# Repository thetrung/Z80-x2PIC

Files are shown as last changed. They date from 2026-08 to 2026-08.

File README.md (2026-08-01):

# Z80 Homebrew with Dual 8-bit PIC 
Another PCB made for Z80 + 2x PIC18F4520 to debug, test-run & verify code.

### Note
I have never had a real working Z80 before so this board is designed to test that if I can get one.

### 3D Preview 
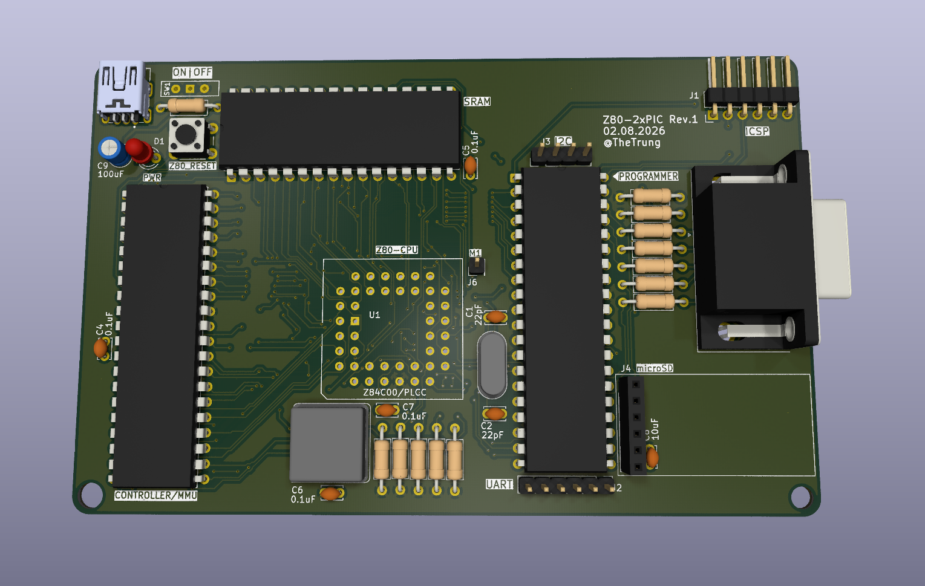
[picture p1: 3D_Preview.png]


### Placement (SilkScreen)
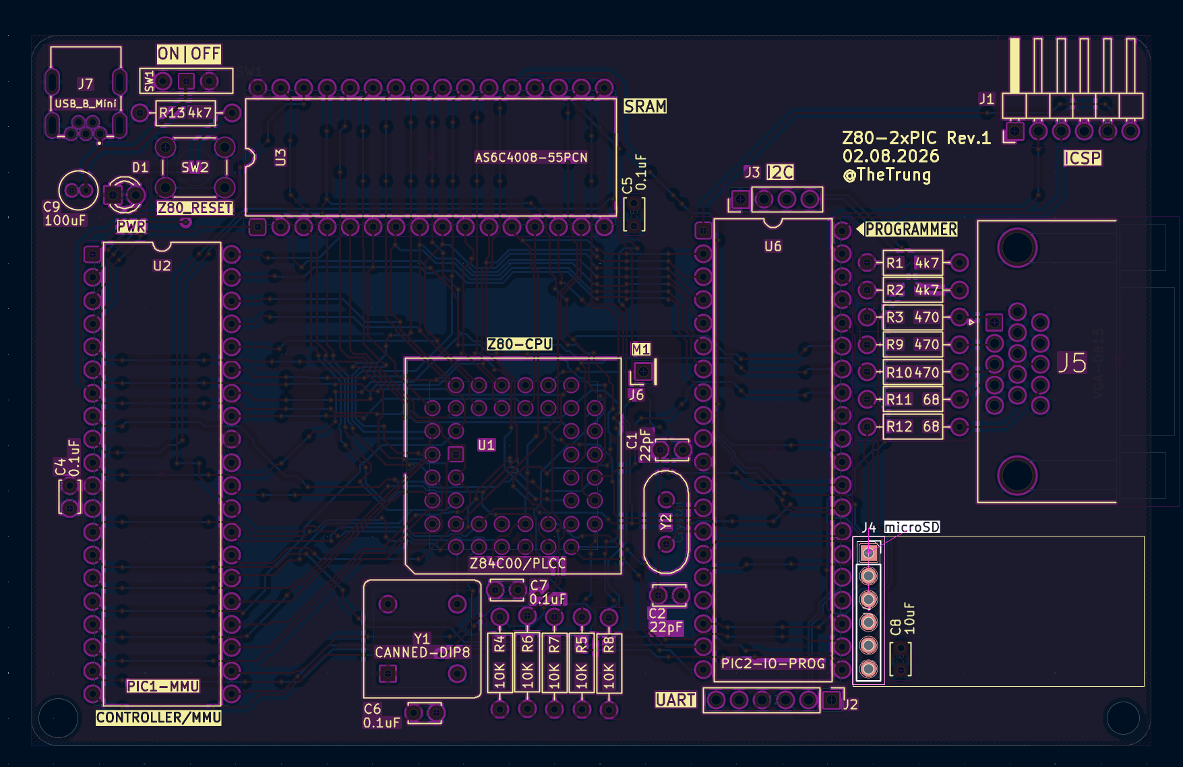
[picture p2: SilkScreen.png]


### Schematic 
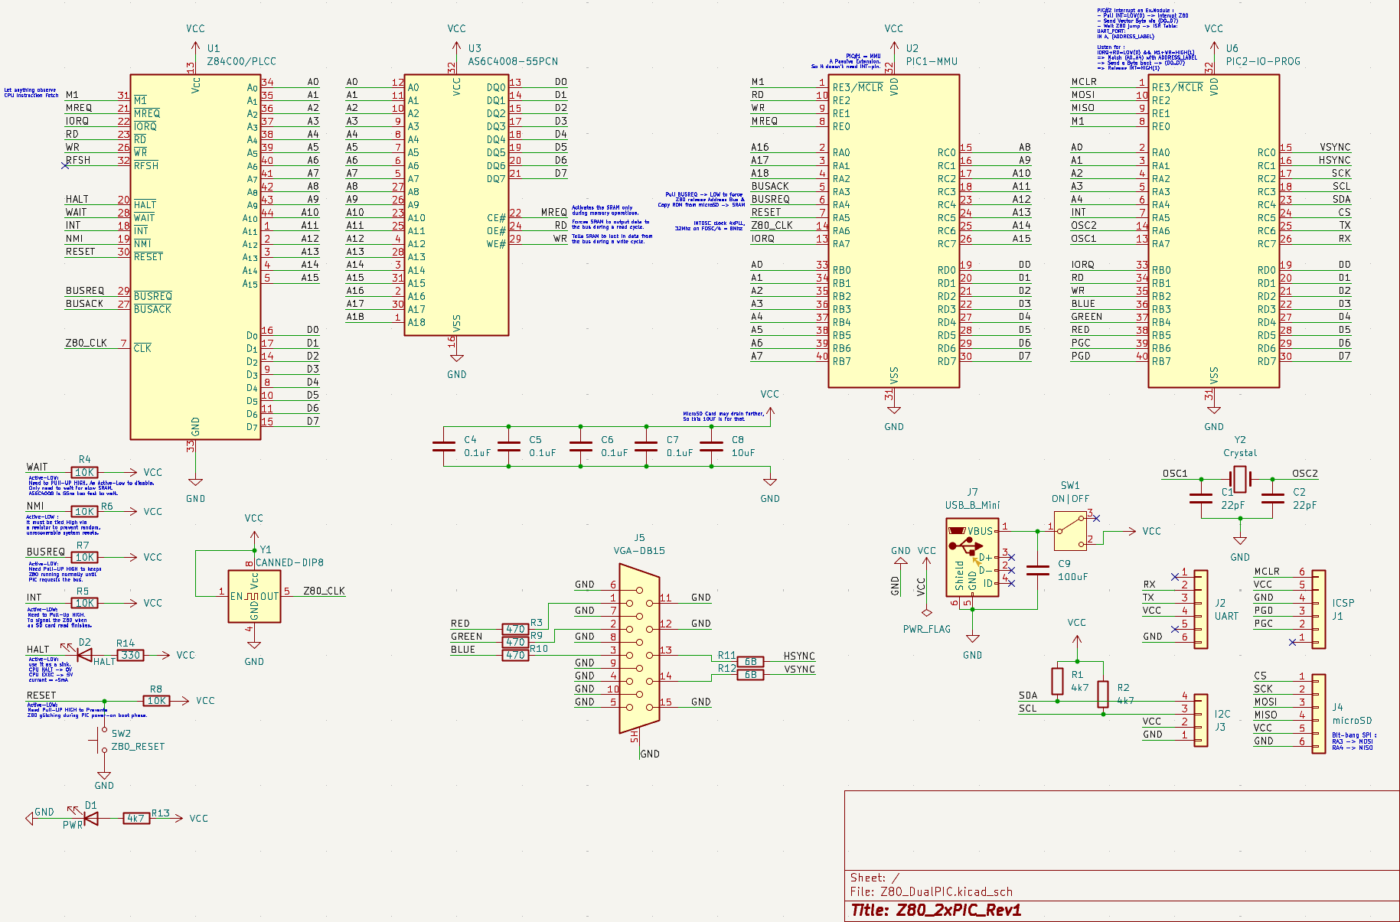
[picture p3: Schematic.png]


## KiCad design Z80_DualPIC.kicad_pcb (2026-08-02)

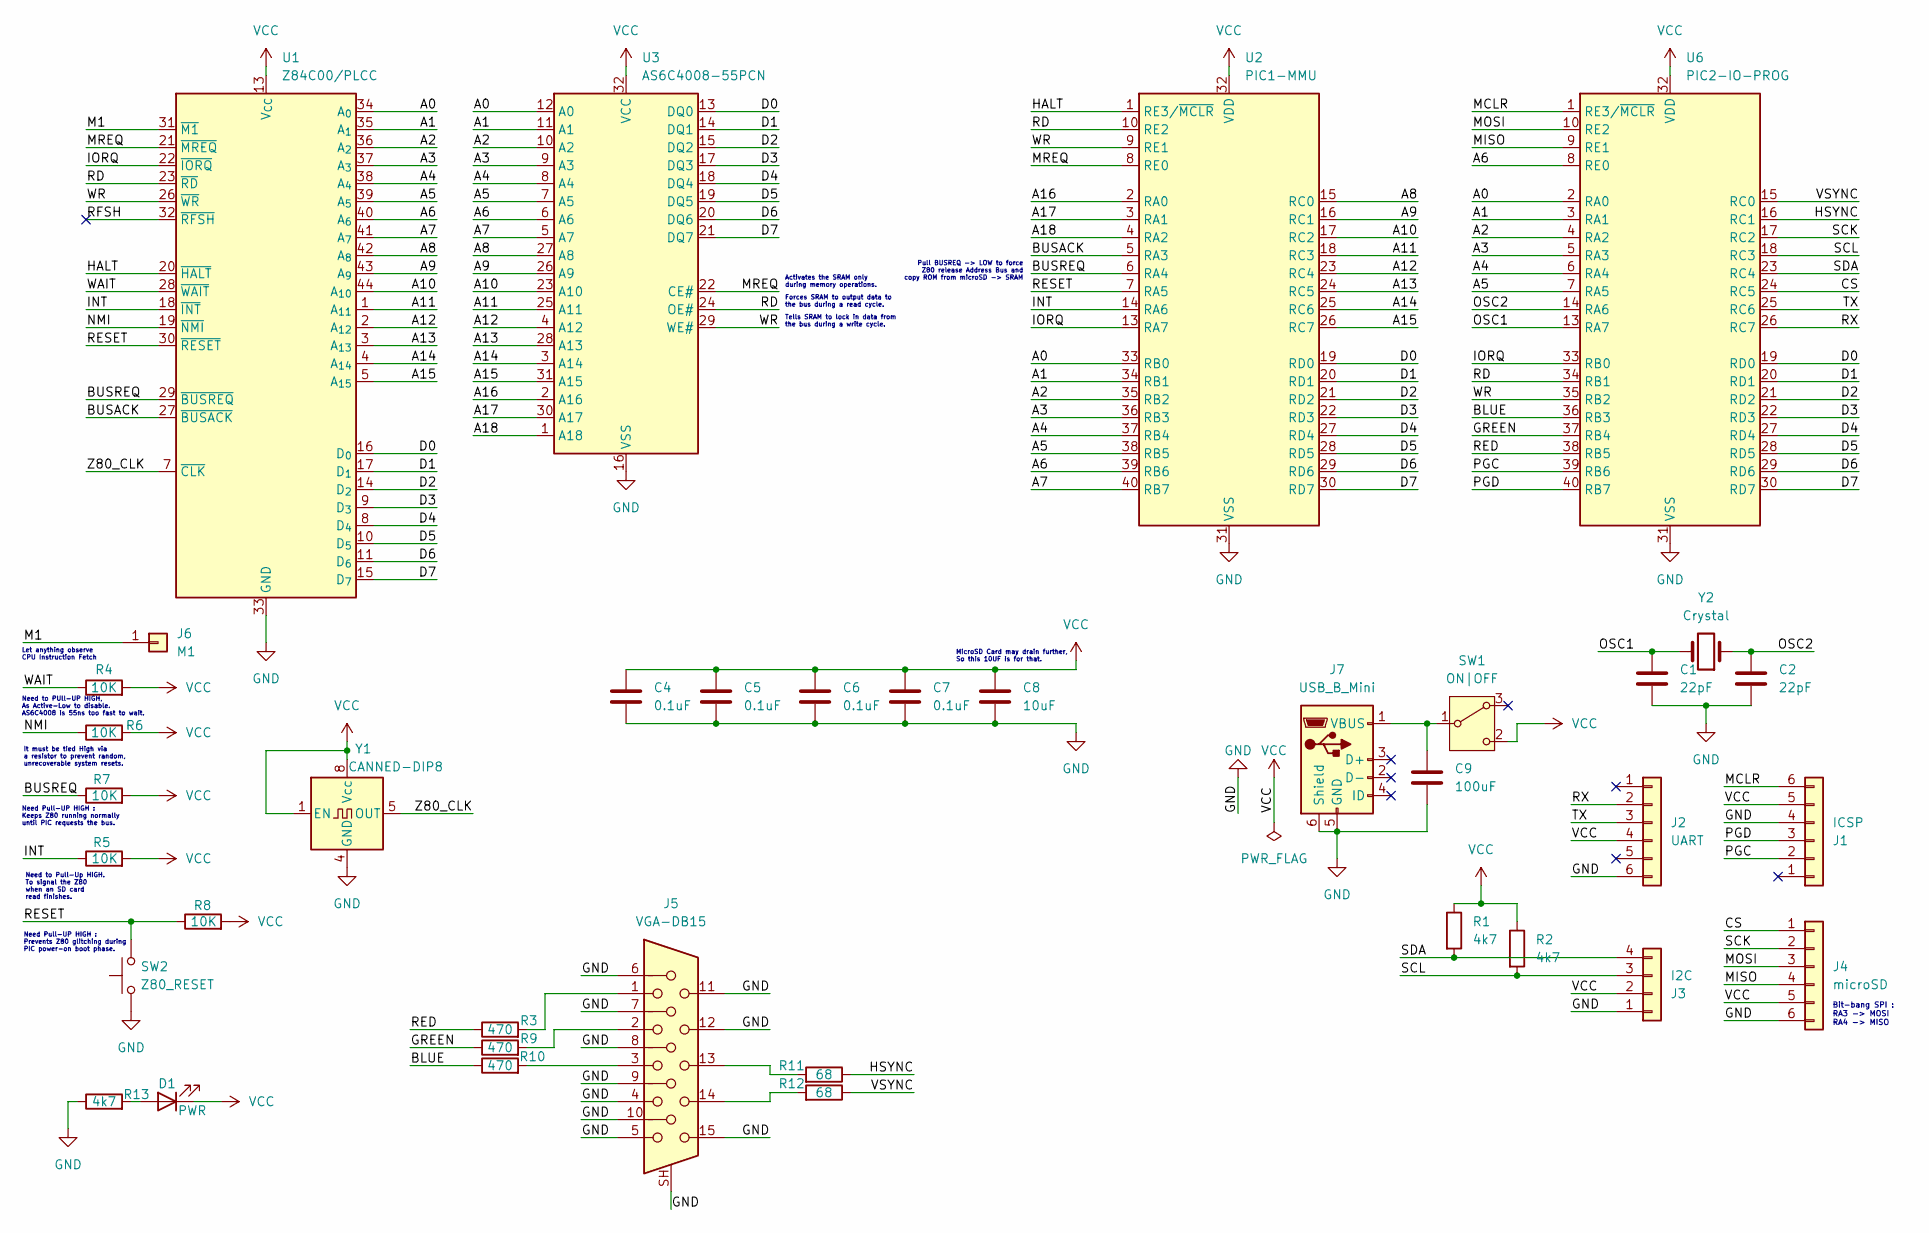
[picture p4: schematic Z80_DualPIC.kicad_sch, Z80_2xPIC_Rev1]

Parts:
C1, C2: 22pF; C_Disc_D3.4mm_W2.1mm_P2.50mm
C4, C5, C6, C7: 0.1uF; C_Disc_D3.4mm_W2.1mm_P2.50mm
C8: 10uF; C_Disc_D3.4mm_W2.1mm_P2.50mm
C9: 100uF; C_Radial_D4.0mm_H5.0mm_P1.50mm
D1: PWR; LED_D3.0mm
J1: ICSP; PinHeader_1x06_P2.54mm_Horizontal
J2: UART; PinHeader_1x06_P2.54mm_Vertical
J3: I2C; PinHeader_1x04_P2.54mm_Vertical
J4: microSD; PinSocket_1x06_P2.54mm_Vertical
J5: VGA-DB15; DSUB-15-HD_Socket_Horizontal_P2.29x2.54mm_EdgePinOffset8.35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
J6: M1; PinHeader_1x01_P2.54mm_Vertical
J7: USB_B_Mini; USB_MINI_B_90_Angled
R1, R2, R13: 4k7; R_Axial_DIN0207_L6.3mm_D2.5mm_P10.16mm_Horizontal
R3, R9, R10: 470; R_Axial_DIN0207_L6.3mm_D2.5mm_P10.16mm_Horizontal
R4, R5, R6, R7, R8: 10K; R_Axial_DIN0207_L6.3mm_D2.5mm_P10.16mm_Horizontal
R11, R12: 68; R_Axial_DIN0207_L6.3mm_D2.5mm_P10.16mm_Horizontal
SW1: ON|OFF; SW_Slide-03_Wuerth-WS-SLTV_10x2.5x6.4_P2.54mm
SW2: Z80_RESET; SW_PUSH_6mm
U1: Z84C00/PLCC; PLCC-44_THT-Socket
U2: PIC1-MMU; DIP-40_W15.24mm
U3: AS6C4008-55PCN; DIP-32_W15.24mm
U6: PIC2-IO-PROG; DIP-40_W15.24mm
Y1: CANNED-DIP8; Oscillator_DIP-8
Y2: Crystal; Crystal_HC49-4H_Vertical

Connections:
/A0: U1.34 (A_{0}), U2.33 (RB0), U3.12 (A0), U6.2 (RA0)
/A1: U1.35 (A_{1}), U2.34 (RB1), U3.11 (A1), U6.3 (RA1)
/A2: U1.36 (A_{2}), U2.35 (RB2), U3.10 (A2), U6.4 (RA2)
/A3: U1.37 (A_{3}), U2.36 (RB3), U3.9 (A3), U6.5 (RA3)
/A4: U1.38 (A_{4}), U2.37 (RB4), U3.8 (A4), U6.6 (RA4)
/A5: U1.39 (A_{5}), U2.38 (RB5), U3.7 (A5), U6.7 (RA5)
/A6: U1.40 (A_{6}), U2.39 (RB6), U3.6 (A6), U6.8 (RE0)
/A7: U1.41 (A_{7}), U2.40 (RB7), U3.5 (A7)
/A8: U1.42 (A_{8}), U2.15 (RC0), U3.27 (A8)
/A9: U1.43 (A_{9}), U2.16 (RC1), U3.26 (A9)
/A10: U1.44 (A_{10}), U2.17 (RC2), U3.23 (A10)
/A11: U1.1 (A_{11}), U2.18 (RC3), U3.25 (A11)
/A12: U1.2 (A_{12}), U2.23 (RC4), U3.4 (A12)
/A13: U1.3 (A_{13}), U2.24 (RC5), U3.28 (A13)
/A14: U1.4 (A_{14}), U2.25 (RC6), U3.3 (A14)
/A15: U1.5 (A_{15}), U2.26 (RC7), U3.31 (A15)
/A16: U2.2 (RA0), U3.2 (A16)
/A17: U2.3 (RA1), U3.30 (A17)
/A18: U2.4 (RA2), U3.1 (A18)
/BLUE: R10.1, U6.36 (RB3)
/BUSACK: U1.27 (~BUSACK), U2.5 (RA3)
/BUSREQ: R7.1, U1.29 (~BUSREQ), U2.6 (RA4)
/CS: J4.1, U6.24 (RC5)
/D0: U1.16 (D_{0}), U2.19 (RD0), U3.13 (DQ0), U6.19 (RD0)
/D1: U1.17 (D_{1}), U2.20 (RD1), U3.14 (DQ1), U6.20 (RD1)
/D2: U1.14 (D_{2}), U2.21 (RD2), U3.15 (DQ2), U6.21 (RD2)
/D3: U1.9 (D_{3}), U2.22 (RD3), U3.17 (DQ3), U6.22 (RD3)
/D4: U1.8 (D_{4}), U2.27 (RD4), U3.18 (DQ4), U6.27 (RD4)
/D5: U1.10 (D_{5}), U2.28 (RD5), U3.19 (DQ5), U6.28 (RD5)
/D6: U1.11 (D_{6}), U2.29 (RD6), U3.20 (DQ6), U6.29 (RD6)
/D7: U1.15 (D_{7}), U2.30 (RD7), U3.21 (DQ7), U6.30 (RD7)
/GREEN: R9.1, U6.37 (RB4)
/HALT: U1.20 (~HALT), U2.1 (RE3/~MCLR)
/HSYNC: R11.1, U6.16 (RC1)
/INT: R5.1, U1.18 (~INT), U2.14 (RA6)
/IORQ: U1.22 (~IORQ), U2.13 (RA7), U6.33 (RB0)
/M1: J6.1 (Pin_1_1), U1.31 (~M1)
/MCLR: J1.6, U6.1 (RE3/~MCLR)
/MISO: J4.4, U6.9 (RE1)
/MOSI: J4.3, U6.10 (RE2)
/MREQ: U1.21 (~MREQ), U2.8 (RE0), U3.22 (CE#)
/NMI: R6.1, U1.19 (~NMI)
/OSC1: C1.1, U6.13 (RA7), Y2.2
/OSC2: C2.1, U6.14 (RA6), Y2.1
/PGC: J1.2, U6.39 (RB6)
/PGD: J1.3, U6.40 (RB7)
/RD: U1.23 (~RD), U2.10 (RE2), U3.24 (OE#), U6.34 (RB1)
/RED: R3.1, U6.38 (RB5)
/RESET: R8.1, SW2.2, U1.30 (~RESET), U2.7 (RA5)
/RFSH: U1.32 (~RFSH)
/RX: J2.2, U6.26 (RC7)
/SCK: J4.2, U6.17 (RC2)
/SCL: J3.3, R2.2, U6.18 (RC3)
/SDA: J3.4, R1.2, U6.23 (RC4)
/TX: J2.3, U6.25 (RC6)
/VSYNC: R12.1, U6.15 (RC0)
/WAIT: R4.1, U1.28 (~WAIT)
/WR: U1.26 (~WR), U2.9 (RE1), U3.29 (WE#), U6.35 (RB2)
/Z80_CLK: U1.7 (~CLK), Y1.5 (OUT)
GND: C1.2, C2.2, C4.1, C5.1, C6.1, C7.1, C8.1, C9.1, J1.4, J2.6, J3.1, J4.6, J5.4, J5.5, J5.6, J5.7, J5.8, J5.9, J5.10, J5.11, J5.12, J5.15, J5.SH, J7.5 (GND), J7.6 (Shield), R13.1, SW2.1, U1.33 (GND), U2.12 (VSS), U2.31 (VSS), U3.16 (VSS), U6.12 (VSS), U6.31 (VSS), Y1.4 (GND)
unnamed: D1.2 (A), R13.2
unnamed: J5.1, R3.2
unnamed: J5.2, R9.2
unnamed: J5.3, R10.2
unnamed: J5.13, R11.2
unnamed: J5.14, R12.2
unnamed: C9.2, J7.1 (VBUS), SW1.1 (B)
VCC: C4.2, C5.2, C6.2, C7.2, C8.2, D1.1 (K), J1.5, J2.4, J3.2, J4.5, R1.1, R2.1, R4.2, R5.2, R6.2, R7.2, R8.2, SW1.2 (C), U1.13 (V_{CC}), U2.11 (VDD), U2.32 (VDD), U3.32 (VCC), U6.11 (VDD), U6.32 (VDD), Y1.1 (EN), Y1.8 (Vcc)

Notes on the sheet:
Activates the SRAM only during memory operations.
Bit-bang SPI : RA3 -> MOSI RA4 -> MISO
Need to Pull-Up HIGH. To signal the Z80 when an SD card read finishes.
Forces SRAM to output data to the bus during a read cycle.
It must be tied High via a resistor to prevent random, unrecoverable system resets.
MicroSD Card may drain further, So this 10UF is for that.
Need Pull-UP HIGH : Prevents Z80 glitching during PIC power-on boot phase.
Pull BUSREQ -> LOW to force Z80 release Address Bus and copy ROM from microSD -> SRAM
Need to PUll-UP HIGH, As Active-Low to disable. AS6C4008 is 55ns too fast to wait.
Need Pull-UP HIGH : Keeps Z80 running normally until PIC requests the bus.
Let anything observe CPU Instruction Fetch
Tells SRAM to lock in data from the bus during a write cycle.

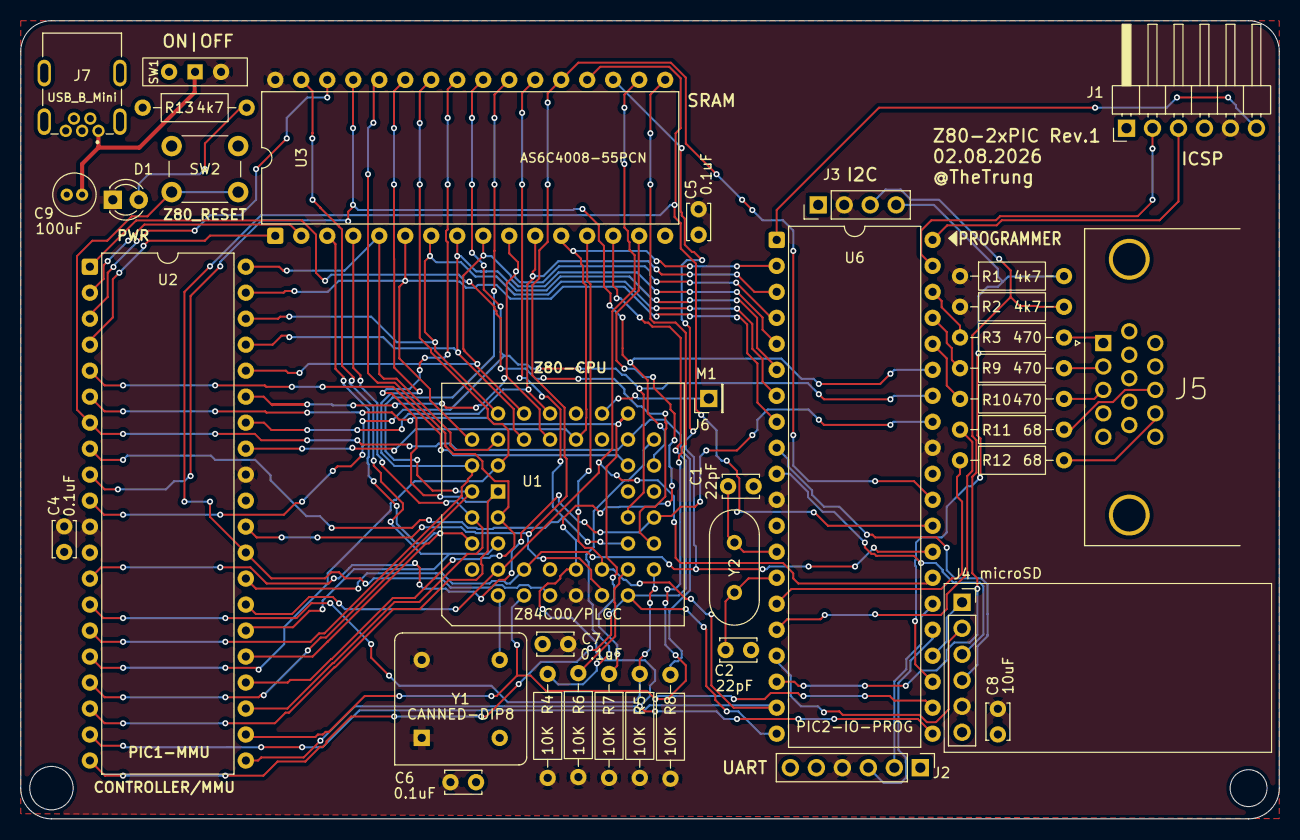
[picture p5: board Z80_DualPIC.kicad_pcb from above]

Board: 2 copper layers, 123.0 x 78.0 mm, 37 parts (0 on the bottom side), 67 nets.

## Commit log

2026-08-01 Init Z80 + 2xPIC18 Setup.
    [Z80_DualPIC.kicad_pcb, Z80_DualPIC.kicad_sch]
2026-08-01 finish routing & added README.md
    [Z80_DualPIC.kicad_pcb, Z80_DualPIC.kicad_sch]
2026-08-02 add IORQ, WR, RD & A0~A6 into PIC#2
    [Z80_DualPIC.kicad_pcb, Z80_DualPIC.kicad_sch]
2026-08-02 Refine routes + microSD placement.
    [Z80_DualPIC.kicad_pcb]
2026-08-02 add CLK to pulse Z80 clock + interrupt pins.
    [Z80_DualPIC.kicad_sch]
